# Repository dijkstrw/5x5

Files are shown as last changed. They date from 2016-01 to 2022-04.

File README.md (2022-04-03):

5x5 aka Gojira!
===============

This is my first custom keyboard, a 5x5 cherry mx matrix based on the STM32F1
with libopencm3. The project contains firmware, schematics and a board layout
in kicad.

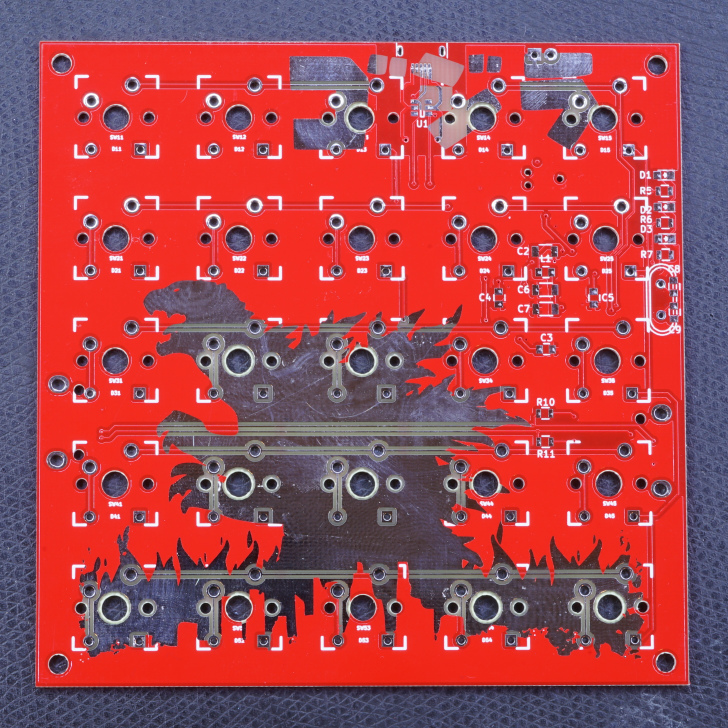
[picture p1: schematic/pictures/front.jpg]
Board Front Picture


This project is intended as a platform for custom keyboard development. It
supports:
- usb keyboard scancodes
- bios boot and nkro
- system / consumer codes
- generation of mouse events
- usb serial interface
- an automouse mode for fast-clicking
- programmable macro keys via serial
- storing current configuration in "userflash"

The board is programmed using a 6-pin TagConnect, that must be wired
to a STM Discovery SWD/STLink programming port.

Building
========

    git submodule init
    git submodule update
    make -C libopencm3
    make

Features
========

Keyboards
---------

The board provides 3 types of keyboards via different usb
endpoints.

1. The first is the usb standard bios keyboard definition, which
   allows the keyboard also to emit key codes to hosts with limited
   usb hid support. (This used to be the case in <2015 style bioses,
   hence the name.)

2. The second keyboard is a n-key-rollover, which exposes a keyboard
   that allows 224 usb keyboard scancodes to be pressed
   simultaneously. Also, because we do not need to adhere to the bios
   boot standard, this endpoint's interval can set much lower = it
   types much faster.

3. The third keyboard can emit so called consumer and system
   codes. Example consumer key codes are PLAY, PAUSE, but also MARK,
   CLEARMARK, REPEATFROMMARK. So everything the typical multimedia
   keys emit and then some.

Mouse
-----

Operate the rodent from your keyboard! There is support for x, y, 5
buttons and a vertical and horizontal scrollwheel action.

Serial
------

The board exposes a serial port for logging, and
configuration. Commands available are:

    ? - show a terse description of available commands.

    i - show usb info strings; contains the git-describe tag of the
        current firmware, so mission critical to some, useless to
        everybody else.

    d - dump the keymap(s).

    K - redefine a key in the keymap, takes a hexadecimal argument of
        the form <layer><row><column><type><arg1><arg2><arg3>, with each
        argument being 2 digits long.

    m - clear all macro keys.

    M - define one macro key, takes an argument of the form
        <number><oftenusedstring>. The number is a two hexdigits, the
        string can be upto 32 7-bit ascii chars long and is terminated
        with a newline.

    n - set keyboard mode to bios (default).

    N - set keyboard mode to nkro.

    R - read configuration from flash

    W - write configuration to flash

    Z - clear the configration flash, revert to "factory" keymap at
        next powerup.

Command interpretation starts after receiving a newline.

Automouse
---------

Automouse is a mouse clicker, with optional speed setting and wiggle
amounts. This allows you to click real fast, and wiggle the mouse
while using your hands for something else.

Macros
------

Macros set via serial are lost at power off unless the configuration
is written to flash. Loading from flash happens automatically at
powerup.

The strings that you provide via serial need to be translated into usb
keycodes, so currently only 7-bit ascii strings are supported.

Setting macros via the shell is easy:

    echo -e "\nM01Nevergonnagiveyouup!\n" > /dev/ttyACM0

Notes:

- The initial newline is a trick to make sure our M will be considered
  the start of a command, no matter what has been put to the serial
  before by you, some driver or the os.
- This particular example defines the macro for macro key number 1.
- You need to have a macro key 1 in your keymap, otherwise you have
  nothing to trigger the macro.

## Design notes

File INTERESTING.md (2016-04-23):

Interesting
===========

While working on a project I collect my own questions and they answers I
found + add in interesting gotchas encountered along the way.

* There are a lot of parts to an usb descriptor. How are they tied together?

    Device Desc -> Configuration Desc -> Interface Desc -> Endpoint Desc / HID Desc
    if HID Desc -> Report Desc / Physical Desc

    (p 16, USB HID 1.11)

* Wat is the purpose of SOF?

    Start of Frame, issued every millisecond by the host. The SOF interrupt can
    be used to drive routines that need to work timeouts.

* How many different usb devices can the stm32f1 pretend to be?

    One usb device, but with 8 endpoints. I'm using 7 so far for keyboard,
    mouse, nkro, extra keys, cdc comm, cdc in and cdc out.

* What is needed in a usb boot keyboard descriptor?

    HID Report parsing is large, so for bios boot support a special HID
    subclass is supported that identifies a predefined protocol for
    mouse/keyboards. The boot protocol can be extended to include additional
    data not recognized by the BIOS, or the device can support a second
    preferred protocol for use by the HID driver.

    bInterfaceSubClass = 0 /* No Subclass */
    bInterfaceSubClass = 1 /* Boot interface subclass */

* STM32F1 errata: Some Cortex-M3 have a silicon error, although mine is reputed
  to not have it, enable -mfix-cortex-m3-ldrd

* STM32F1 errata: USB operation may have a bug if APB1 clock is lower than
  13MHz

* Never send a different amount of bytes than the amount promised in your
  descriptor. Deviation = linux driver error, that prompts the stm to resend,
  ad nauseam.

Debugging USB
-------------

Being able to debug usb turned out to be essential. wireshark can capture usb
packets and show their disassembly. Faulty packets are not always displayed
(for instance if in the case of physical packet errors), but still provide a
smoking gun for fault analysis.

        modprobe usbmon
        wireshark

If the initial usb negotiation fails, the kernel will ignore the attached
device. Reconnecting the usb plug will restart the negotiation, but is not
always convenient when you have a debugger on the usb keyboard waiting for an
interesting breakpoint. There is a utility in util/usbreset that will reset the
usb bus and restart negotiation without having to replug the connector. E.g.

       ./util/usbreset /dev/bus/usb/005/002

Where /dev/bus/usb/005/002 is the keyboard device to be reset.

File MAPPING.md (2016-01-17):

Mapping keys
============

Physical keys are mapped to usb scan codes. Usb scancodes are mapped to linux
scancodes. Scancodes are mapped to keycodes, which in turn are mapped to
keysyms. A keycode corresponds to a function, a keysym may change if a keyboard
modifier (i.e. shift is active)

Usb scancodes
-------------

Keyboards that are attached via usb hid can emit 255 different
scancodes. Inside the linux kernel, only about half of these usb scancodes are
mapped to linux scancodes (see linux/drivers/hid/usbhid/usbkbd.c). The unmapped
half are declared unknown, but can be enabled by first looking at their real
value using evtest:

      evtest
      Properties:
      Testing ... (interrupt to exit)
      Event: time 1451422547.619719, type 4 (EV_MSC), code 4 (MSC_SCAN), value 7008b
      Event: time 1451422547.619719, type 1 (EV_KEY), code 471 (KEY_FN_F6), value 1
      Event: time 1451422547.619719, -------------- SYN_REPORT ------------
      Event: time 1451422547.675713, type 4 (EV_MSC), code 4 (MSC_SCAN), value 7008b
      Event: time 1451422547.675713, type 1 (EV_KEY), code 471 (KEY_FN_F6), value 0
      Event: time 1451422547.675713, -------------- SYN_REPORT ------------

And then adjusting the udev hwdb /etc/udev/hwdb.d/70-keyboard.hwdb:

    evdev:input:b0003vDEADpBEEF*
     KEYBOARD_KEY_70086=fn_f1
     KEYBOARD_KEY_70087=fn_f2
     KEYBOARD_KEY_70088=fn_f3
     KEYBOARD_KEY_70089=fn_f4
     KEYBOARD_KEY_7008a=fn_f5
     KEYBOARD_KEY_7008b=fn_f6
     KEYBOARD_KEY_7008c=fn_f7
     KEYBOARD_KEY_7008d=fn_f8
     KEYBOARD_KEY_7008e=fn_f9
     KEYBOARD_KEY_7008f=fn_f10

Update the hwdb, and trigger a reload

    udevadm hwdb --update
    udevadm trigger /dev/input/event*

and after that the linux kernel will map the usb scancodes to linux scancodes.

Keycodes
--------

Linux scancode to keycode mapping for X happens through the mappings provided
by xkb. "xmodmap is a decade out of date" -- man that made me feel old. From
what I can find, these are still only max 255 keycodes possible, so mapping to
unused codes <255 seems "key".

This made me rethink the whole mapping approach described above. I would have
liked to define my own partitioned off set of keys, and not interfere with
other keys present. The last mapping step precludes this, so why go to the
trouble in the first place. I reset my initial keyboard layer to just use the
media keys, F13-F20 and the numeric keypad. None of these are present on my
normal tkl-keyboard, and all are present in the default usb-hid -> linux
scancodes -> X keycode -> X keysym mappings.

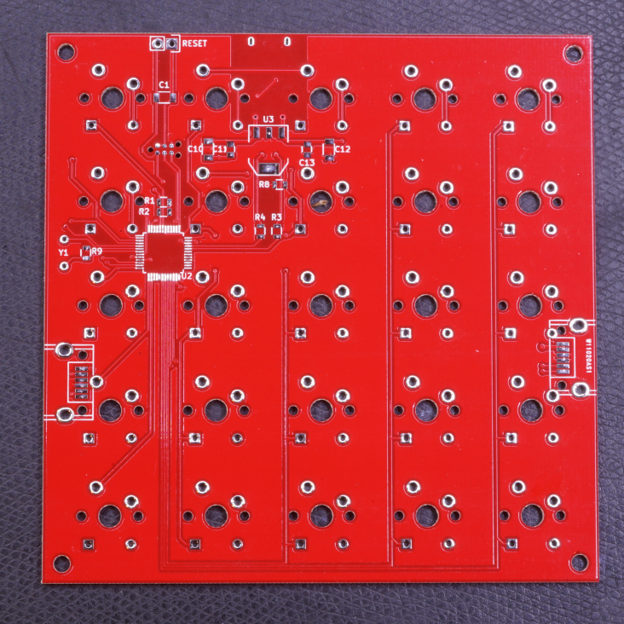
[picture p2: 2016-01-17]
schematic/pictures/back.jpg

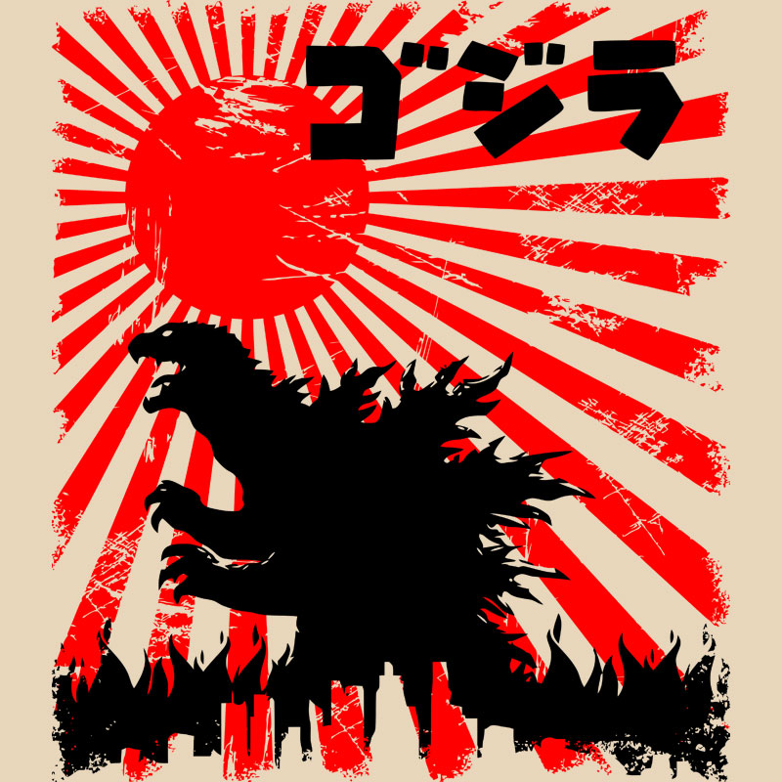
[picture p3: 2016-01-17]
schematic/gojira.jpg

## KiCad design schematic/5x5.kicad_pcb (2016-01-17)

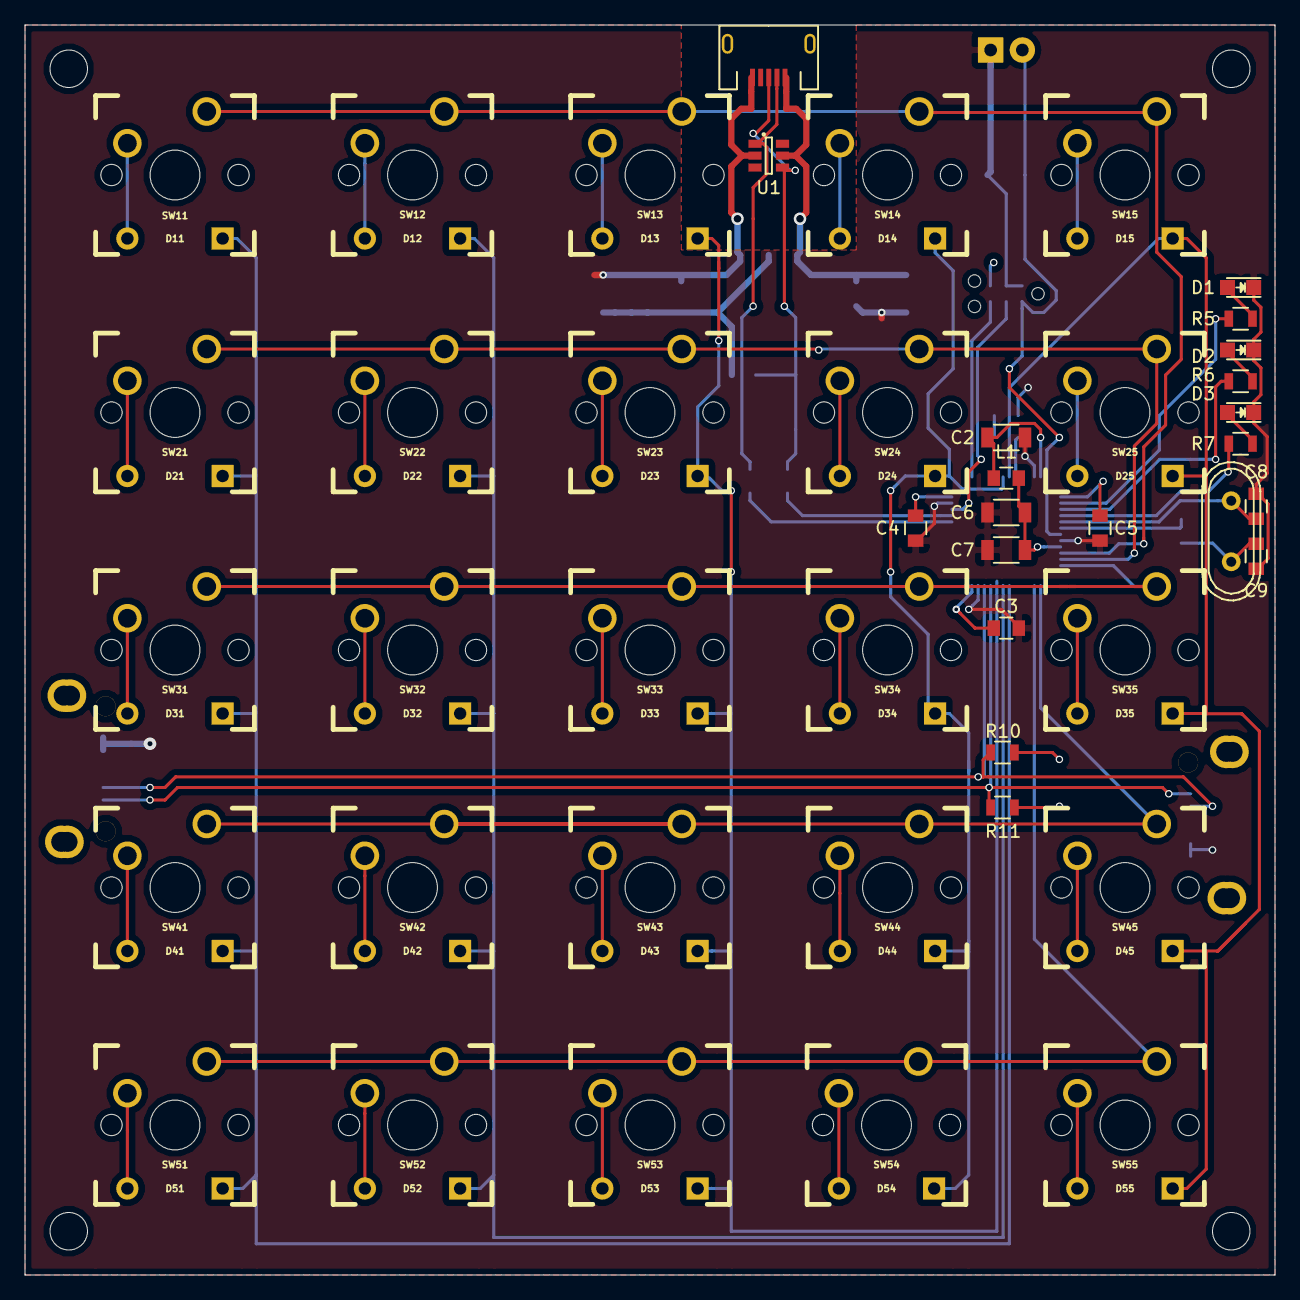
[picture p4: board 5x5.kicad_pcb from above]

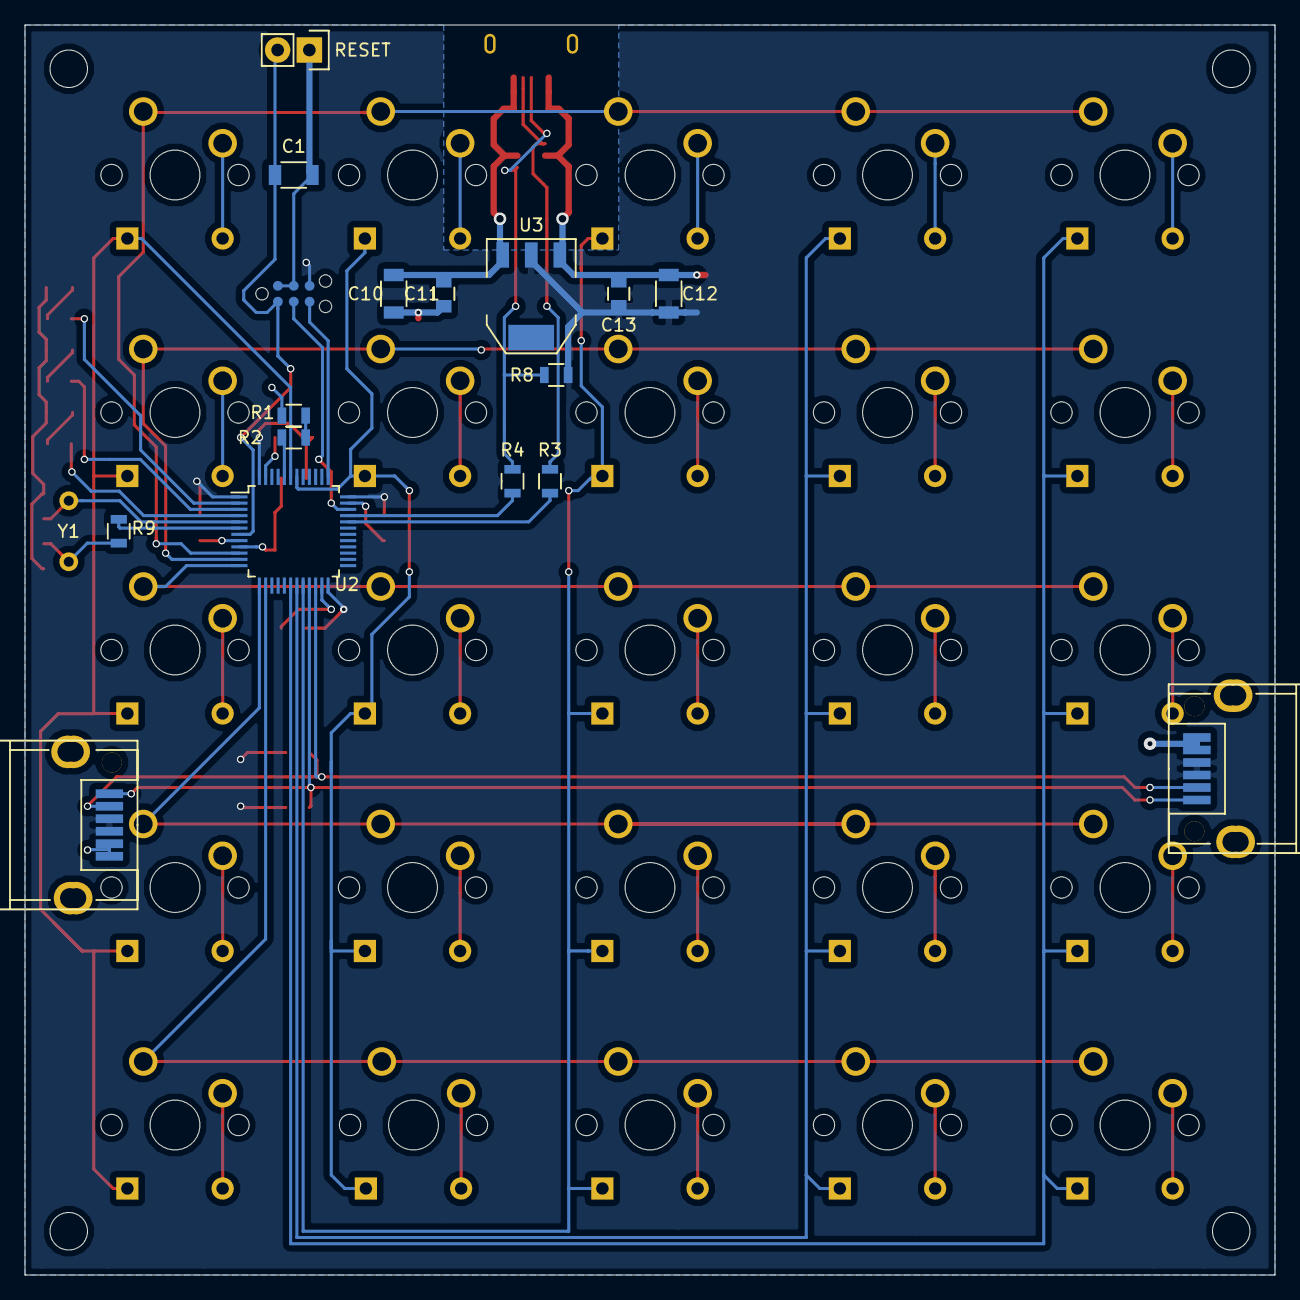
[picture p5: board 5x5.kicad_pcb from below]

Board: 2 copper layers, 100.0 x 100.0 mm, 87 parts (17 on the bottom side), 59 nets.

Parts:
C1: 100n; C_1206
C2, C12: 10u; C_1206
C3, C4, C5, C11, C13: 100n; C_0805
C6, C10: 1u; C_1206
C7: 1n; C_1206
C8, C9: 20p; C_0805
D1, D2, D3: Led_Small; LED-0805
D11, D12, D13, D14, D15, D21, D22, D23, D24, D25, D31, D32, D33, D34, D35, D41, D42, D43, D44, D45, D51, D52, D53, D54, D55: 1N4148; CHERRY_MX_DIODE
L1: bead; C_0805
P1: JTAG_SWDP; TC2030-IDC-NL
P2: USB-B; FCI-10118193-0001LF
P5: I2CI; Harwin-M702-230642
P6: I2CO; Harwin-M702-230642
R1: 10k; R_0805
R2: 0; R_0805
R3, R4: 22; R_0805
R5, R6, R7: 1k; R_0805
R8: 1k5; R_0805
R9: 33; R_0805
R10, R11: 4k7; R_0805
RESET: SW; Pin_Header_Straight_1x02
SW11, SW12, SW13, SW14, SW15, SW21, SW22, SW23, SW24, SW25, SW31, SW32, SW33, SW34, SW35, SW41, SW42, SW43, SW44, SW45, SW51, SW52, SW53, SW54, SW55: SW; CHERRY_PCB_100H
U1: MAX3207E; SOT-23-6
U2: STM32F103C8; LQFP-48_7x7mm_Pitch0.5mm
U3: LD1117S33CTR; SOT-223
Y1: 16M; Crystal_HC49-U_Vertical

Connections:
+3V3: C2.1, C3.1, C4.1, C5.1, C12.1, C13.1, L1.1, P1.6, P5.3, P5.4, P6.3, P6.4, R8.2, R10.2, R11.2, U2.1, U2.24, U2.36, U2.48, U3.2
COL1: D11.1, D21.1, D31.1, D41.1, D51.1, U2.18
COL2: D12.1, D22.1, D32.1, D42.1, D52.1, U2.19
COL3: D13.1, D23.1, D33.1, D43.1, D53.1, U2.20
COL4: D14.1, D24.1, D34.1, D44.1, D54.1, U2.42
COL5: D15.1, D25.1, D35.1, D45.1, D55.1, U2.43
GND: C1.2, C2.2, C3.2, C4.2, C5.2, C6.2, C7.2, C8.1, C9.1, C10.2, C11.2, C12.2, C13.2, D1.1, D2.1, D3.1, P1.2, P1.4, P2.5, P5.5, P5.6, P6.5, P6.6, R2.2, RESET.1, U1.2, U2.8, U2.23, U2.35, U2.47, U3.1
unnamed: C1.1, P1.1, RESET.2, U2.7
unnamed: C6.1, C7.1, L1.2, U2.9
unnamed: C8.2, U2.5, Y1.1
unnamed: C9.2, R9.1, Y1.2
unnamed: D1.2, R5.1
unnamed: D2.2, R6.1
unnamed: D3.2, R7.1
unnamed: D11.2, SW11.2
unnamed: D12.2, SW12.2
unnamed: D13.2, SW13.2
unnamed: D14.2, SW14.2
unnamed: D15.2, SW15.2
unnamed: D21.2, SW21.2
unnamed: D22.2, SW22.2
unnamed: D23.2, SW23.2
unnamed: D24.2, SW24.2
unnamed: D25.2, SW25.2
unnamed: D31.2, SW31.2
unnamed: D32.2, SW32.2
unnamed: D33.2, SW33.2
unnamed: D34.2, SW34.2
unnamed: D35.2, SW35.2
unnamed: D41.2, SW41.2
unnamed: D42.2, SW42.2
unnamed: D43.2, SW43.2
unnamed: D44.2, SW44.2
unnamed: D45.2, SW45.2
unnamed: D51.2, SW51.2
unnamed: D52.2, SW52.2
unnamed: D53.2, SW53.2
unnamed: D54.2, SW54.2
unnamed: D55.2, SW55.2
unnamed: P1.3, U2.34
unnamed: P1.5, U2.37
unnamed: P2.2, R3.2, U1.1
unnamed: P2.3, R4.2, R8.1, U1.4
unnamed: R1.1, U2.44
unnamed: R1.2, R2.1
unnamed: R3.1, U2.32
unnamed: R4.1, U2.33
unnamed: R5.2, U2.2
unnamed: R6.2, U2.3
unnamed: R7.2, U2.4
unnamed: R9.2, U2.6
ROW1: SW11.1, SW12.1, SW13.1, SW14.1, SW15.1, U2.10
ROW2: SW21.1, SW22.1, SW23.1, SW24.1, SW25.1, U2.11
ROW3: SW31.1, SW32.1, SW33.1, SW34.1, SW35.1, U2.12
ROW4: SW41.1, SW42.1, SW43.1, SW44.1, SW45.1, U2.13
ROW5: SW51.1, SW52.1, SW53.1, SW54.1, SW55.1, U2.14
SCL: P5.1, P6.1, R11.1, U2.21
SDA: P5.2, P6.2, R10.1, U2.22
Vusb: C10.1, C11.1, P2.1, U1.5, U3.3

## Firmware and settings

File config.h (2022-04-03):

/*
 * Copyright (c) 2015-2016 by Willem Dijkstra <wpd@xs4all.nl>.
 * All rights reserved.
 *
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
 * THIS SOFTWARE IS PROVIDED BY THE COPYRIGHT HOLDERS AND CONTRIBUTORS "AS IS" AND
 * ANY EXPRESS OR IMPLIED WARRANTIES, INCLUDING, BUT NOT LIMITED TO, THE IMPLIED
 * WARRANTIES OF MERCHANTABILITY AND FITNESS FOR A PARTICULAR PURPOSE ARE
 * DISCLAIMED. IN NO EVENT SHALL THE AUTHOR BE LIABLE FOR ANY
 * DIRECT, INDIRECT, INCIDENTAL, SPECIAL, EXEMPLARY, OR CONSEQUENTIAL DAMAGES
 * (INCLUDING, BUT NOT LIMITED TO, PROCUREMENT OF SUBSTITUTE GOODS OR SERVICES;
 * LOSS OF USE, DATA, OR PROFITS; OR BUSINESS INTERRUPTION) HOWEVER CAUSED AND
 * ON ANY THEORY OF LIABILITY, WHETHER IN CONTRACT, STRICT LIABILITY, OR TORT
 * (INCLUDING NEGLIGENCE OR OTHERWISE) ARISING IN ANY WAY OUT OF THE USE OF THIS
 * SOFTWARE, EVEN IF ADVISED OF THE POSSIBILITY OF SUCH DAMAGE.
 */

#ifndef _CONFIG_H
#define _CONFIG_H

#include "usb.h"

#define USB_GPIO       GPIOA
#define USB_RCC        RCC_GPIOA
#define USB_BV         (GPIO12)
#define SERIAL_BUF_SIZEIN  160
#define SERIAL_BUF_SIZEOUT 1024

/*
 * Matrix pinout definition:
 *
 * PA0-A4 = row driver
 * PB0-B2, B6-B7 = column reader
 *
 * COLS_DECODE is used after column GPIO reading to get a consecutive bitfield
 */

#define ROWS_NUM        5
#define ROWS_GPIO       GPIOA
#define ROWS_RCC        RCC_GPIOA
#define ROWS_BV         0b11111

#define COLS_NUM        5
#define COLS_GPIO       GPIOB
#define COLS_RCC        RCC_GPIOB
#define COLS_BV         0b11000111
#define COLS_DECODE(x)  (((x >> 3) & 0b11000) | (x & 0b111))

#define LAYERS_NUM      5

#define MS_DEBOUNCE     10
#define MS_ENUMERATE    5000

/*
 * Number of macro keys, and max len of a macro sequence
 */
#define MACRO_MAXKEYS   12
#define MACRO_MAXLEN    32

/*
 * Amount of userflash to be used to store the configuration.
 *
 * STM32 flash page size depends on the device:
 * stm32f103xx, with < 128k flash = 1k
 */
#define FLASH_PAGE_NUM  4
#define FLASH_PAGE_SIZE 0x400

#define LEDS_GPIO       GPIOC
#define LEDS_RCC        RCC_GPIOC
#define LEDS_BV         (GPIO13 | GPIO14 | GPIO15)
#define LED1IO          GPIO13
#define LED2IO          GPIO14
#define LED3IO          GPIO15

#define AUTOMOUSE_LED_ACTIVE   (1<<2)
#define AUTOMOUSE_LED_PRESS    (1<<1)
#define MACRO_LED_ACTIVE       (1<<2)

#endif /* _CONFIG_H */

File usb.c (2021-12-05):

/*
 * Copyright (c) 2015-2016 by Willem Dijkstra <wpd@xs4all.nl>.
 * All rights reserved.
 *
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
 * THIS SOFTWARE IS PROVIDED BY THE COPYRIGHT HOLDERS AND CONTRIBUTORS "AS IS" AND
 * ANY EXPRESS OR IMPLIED WARRANTIES, INCLUDING, BUT NOT LIMITED TO, THE IMPLIED
 * WARRANTIES OF MERCHANTABILITY AND FITNESS FOR A PARTICULAR PURPOSE ARE
 * DISCLAIMED. IN NO EVENT SHALL THE AUTHOR BE LIABLE FOR ANY
 * DIRECT, INDIRECT, INCIDENTAL, SPECIAL, EXEMPLARY, OR CONSEQUENTIAL DAMAGES
 * (INCLUDING, BUT NOT LIMITED TO, PROCUREMENT OF SUBSTITUTE GOODS OR SERVICES;
 * LOSS OF USE, DATA, OR PROFITS; OR BUSINESS INTERRUPTION) HOWEVER CAUSED AND
 * ON ANY THEORY OF LIABILITY, WHETHER IN CONTRACT, STRICT LIABILITY, OR TORT
 * (INCLUDING NEGLIGENCE OR OTHERWISE) ARISING IN ANY WAY OUT OF THE USE OF THIS
 * SOFTWARE, EVEN IF ADVISED OF THE POSSIBILITY OF SUCH DAMAGE.
 */

/*
 * USB interface
 *
 * Use the libopencm3 usb stack on top of a stm32f103 to provide usb
 * enumeration as a:
 * - boot usb keyboard
 * - boot usb mouse
 * - usb extrakey that can report <system|consumer> control/application events
 * - nkro usb keyboard
 * - a cdc/acm usb serial port
 */

#include <stdlib.h>
#include <libopencm3/cm3/nvic.h>
#include <libopencm3/cm3/systick.h>
#include <libopencm3/stm32/gpio.h>
#include <libopencm3/stm32/rcc.h>
#include <libopencm3/stm32/spi.h>
#include <libopencm3/stm32/st_usbfs.h>
#include <libopencm3/usb/cdc.h>
#include <libopencm3/usb/hid.h>
#include <libopencm3/usb/usbd.h>

#include "descriptor.h"
#include "elog.h"
#include "extrakey.h"
#include "hid.h"
#include "keyboard.h"
#include "mouse.h"
#include "usb.h"
#include "usb_keycode.h"

static usbd_device *usbd_dev;
volatile uint32_t usb_ms;
volatile uint32_t usb_ifs_enumerated;
volatile uint8_t usb_ep_keyboard_idle;
volatile uint8_t usb_ep_mouse_idle;
volatile uint8_t usb_ep_nkro_idle;
volatile uint8_t usb_ep_extrakey_idle;
volatile uint8_t usb_ep_serial_idle;

/*
 * USB hid
 *
 * Interface, endpoint and hid report definitions for the USB human interface
 * devices we provide.
 */

/*
 * Keyboard boot report, taken from USB HID 1.11 Appendix B
 *
 * Input report (8 bytes):
 * | byte | description   |
 * |------+---------------|
 * |    0 | Modifier keys |
 * |    1 | Reserved      |
 * |    2 | Keycode 1     |
 * |    3 | Keycode 2     |
 * |    4 | Keycode 3     |
 * |    5 | Keycode 4     |
 * |    6 | Keycode 5     |
 * |    7 | Keycode 6     |
 *
 * Output report (1 byte):
 * | bit | description   |
 * |-----+---------------|
 * |   0 | Num Lock      |
 * |   1 | Caps Lock     |
 * |   2 | Scroll Lock   |
 * |   3 | Compose       |
 * |   4 | Kana          |
 * | 5-7 | CONSTANT      |
 */
const uint8_t keyboard_report_descriptor[] = {
    HID_RI_USAGE_PAGE(8, 0x01),                /* Generic Desktop */
    HID_RI_USAGE(8, 0x06),                     /* Keyboard */
    HID_RI_COLLECTION(8, 0x01),                /* Application */
        HID_RI_USAGE_PAGE(8, 0x07),            /* Key Codes */
        HID_RI_USAGE_MINIMUM(8, 0xE0),         /* Keyboard Left Control */
        HID_RI_USAGE_MAXIMUM(8, 0xE7),         /* Keyboard Right GUI */
        HID_RI_LOGICAL_MINIMUM(8, 0x00),
        HID_RI_LOGICAL_MAXIMUM(8, 0x01),
        HID_RI_REPORT_COUNT(8, 0x08),
        HID_RI_REPORT_SIZE(8, 0x01),
        HID_RI_INPUT(8, HID_IOF_DATA | HID_IOF_VARIABLE | HID_IOF_ABSOLUTE),

        HID_RI_REPORT_COUNT(8, 0x01),
        HID_RI_REPORT_SIZE(8, 0x08),
        HID_RI_INPUT(8, HID_IOF_CONSTANT),     /* Reserved */

        HID_RI_USAGE_PAGE(8, 0x08),            /* LEDs */
        HID_RI_USAGE_MINIMUM(8, 0x01),         /* Num Lock */
        HID_RI_USAGE_MAXIMUM(8, 0x05),         /* Kana */
        HID_RI_REPORT_COUNT(8, 0x05),
        HID_RI_REPORT_SIZE(8, 0x01),
        HID_RI_OUTPUT(8, HID_IOF_DATA | HID_IOF_VARIABLE | HID_IOF_ABSOLUTE | HID_IOF_NON_VOLATILE),
        HID_RI_REPORT_COUNT(8, 0x01),
        HID_RI_REPORT_SIZE(8, 0x03),
        HID_RI_OUTPUT(8, HID_IOF_CONSTANT),    /* Led padding */

        HID_RI_USAGE_PAGE(8, 0x07),            /* Keyboard */
        HID_RI_USAGE_MINIMUM(8, 0x00),         /* Reserved (no event indicated) */
        HID_RI_USAGE_MAXIMUM(8, 0xFF),         /* Keyboard Application */
        HID_RI_LOGICAL_MINIMUM(8, 0x00),
        HID_RI_LOGICAL_MAXIMUM(8, 0xFF),
        HID_RI_REPORT_COUNT(8, 0x06),
        HID_RI_REPORT_SIZE(8, 0x08),
        HID_RI_INPUT(8, HID_IOF_DATA | HID_IOF_ARRAY | HID_IOF_ABSOLUTE),
    HID_RI_END_COLLECTION(0),
};

static const struct {
    struct usb_hid_descriptor hid_descriptor;
    struct {
        uint8_t bReportDescriptorType;
        uint16_t wDescriptorLength;
    } __attribute__((packed)) hid_report;
} __attribute__((packed)) keyboard_function = {
    .hid_descriptor = {
        .bLength = sizeof(keyboard_function),
        .bDescriptorType = USB_DT_HID,
        .bcdHID = 0x0111,
        .bCountryCode = 0,
        .bNumDescriptors = 1,
    },
    .hid_report = {
        .bReportDescriptorType = USB_DT_REPORT,
        .wDescriptorLength = sizeof(keyboard_report_descriptor),
    }
};

const struct usb_endpoint_descriptor keyboard_endpoint = {
    .bLength = USB_DT_ENDPOINT_SIZE,
    .bDescriptorType = USB_DT_ENDPOINT,
    .bEndpointAddress = USB_ENDPOINT_ADDR_IN(EP_KEYBOARD),
    .bmAttributes = (USB_ENDPOINT_ATTR_INTERRUPT |
                     USB_ENDPOINT_ATTR_NOSYNC |
                     USB_ENDPOINT_ATTR_DATA),
    .wMaxPacketSize = EP_SIZE_KEYBOARD,
    .bInterval = 0x0A,
};

const struct usb_interface_descriptor keyboard_iface = {
    .bLength = USB_DT_INTERFACE_SIZE,
    .bDescriptorType = USB_DT_INTERFACE,
    .bInterfaceNumber = IF_KEYBOARD,
    .bAlternateSetting = 0,
    .bNumEndpoints = 1,
    .bInterfaceClass = USB_CLASS_HID,
    .bInterfaceSubClass = ID_IS_BOOT,
    .bInterfaceProtocol = ID_IP_KEYBOARD,
    .iInterface = STRI_KEYBOARD,

    .endpoint = &keyboard_endpoint,

    .extra = &keyboard_function,
    .extralen = sizeof(keyboard_function),
};
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

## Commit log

2021-11-22 Better usb interface and added macro keys, and a command channel
    The usb enumeration required all interface to be enumerated before
    freeing the stack to do keyboard interactions. The trouble with this
    approach is that:
    - linux console does not require a mouse, and does not configure that
    interface
    - windows requires a driver for the serial port, and does not
    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
    [jlink.cfg]
2021-11-26 Better cdcacm serial host attach/detach & update readme
    - After looking at stty I noticed that if echo of input is desired
    this can easily be set on the tty. serial.c no longer echos input.
    - Detaching from serial could lead to malformed packets on the
    "out" (note usb host orientation) endpoint. Now we detect an error
    condition, and clear that without looking at the random buffer.
    - All this makes setting the macros easier, but there are still some
    characters that are emitted on the usb bus by the host at the start of
    a serial connection. This makes an initial newline a good idea before
    sending commands over serial.
    - Update the README. "Use the source, Luke" only works when p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
    [usb.c, usb.h]
2021-12-04 Prevent enumeration during bootup
    We now pull down the dp usb pin to disable host enumeration while
    starting up. This reduces the amount of errors during usb attach phase
    + can (in Linux) clear the error status of an usb port.
    [config.h, usb.c, usb.h]
2022-01-07 Improve USB suspend handling
    I misunderstood usb suspend semantics; it is used to indicate that the
    host has had no communication for us for more than 3ms and that we are
    ok to go to a lower power state.
    This does not change the fact that we might have something to say to
    the host. So even in lower power state, we should keep monitoring our
    keys/mouse and issue a "remote wakeup" when such an event occurs.
2022-01-08 Improve usb reset handling
    An usb reset is signalled by the host to (re)start
    enumeration. Enumeration is now a process that:
    - can be (re)started at any time
    - must complete successfully for some of our endpoints, otherwise a
    system reset is forced
    - will halt all normal usb event posting
    [config.h]
2022-01-08 Make led configuration part of config.h
    Currently we have 3 leds which can be set from;
    - keyboard by usb host updates
    - automouse to indicate automouse running
    - macro to indicate macro running
    And each clobbers the other. automouse and macro now only reset the
    leds that they twiddled with.
    [config.h, led.c]
